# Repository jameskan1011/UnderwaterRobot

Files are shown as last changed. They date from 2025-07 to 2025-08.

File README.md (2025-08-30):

# AquaVise: Underwater Inspection Robot

AquaVise is a compact and intelligent underwater Remotely Operated Vehicle (ROV) developed for corrosion inspection and monitoring tasks, specifically within nuclear reactor pools. It combines mechanical agility, advanced sensing, and intelligent software to detect corrosion visually and maintain stable maneuverability in challenging underwater environments.

🏆 **Capstone Theme Award** at Universiti Teknologi Malaysia  
🏆 **Gold Award** in International Virtual Competition of Creative & Innovative Idea (IVCCII 2025)  
🏆 **Gold Medal** in Virtual Innovation Competition 2025  

---
WhatsApp Image 2025-03-29 at 11 39 36 PM (1) (1)
WhatsApp Image 2025-03-29 at 11 39 37 PM

## 📽️ Demonstration

- **Test in Aquarium:**  
https://github.com/user-attachments/assets/d291c60b-21bb-4c5e-aba0-56c1710979f3

- **Pipe Corrosion Detected:**  
corrosion2_crop
corrosion1_crop

- **Adjustable Camera:**
[ezgif-14e0a4dfad839b.webm](https://github.com/user-attachments/assets/6dd5c388-9fd7-4827-bece-901261d9a31d)

---

## 🚀 Features

- **Corrosion Detection**  
  Utilizes OpenCV-based color thresholding to detect yellow-hued corrosion spots.

- **IMU Stabilization**  
  The MPU6050 IMU ensures stability through real-time pitch and roll correction.

- **Compact 3D-Printed Design**  
  The PLA body with epoxy coating is lightweight, waterproof, and environmentally conscious.

- **Four Thruster System**  
  Ensures 6-DOF movement for optimal maneuverability in confined or dynamic underwater spaces.

- **Integrated Control**  
  Arduino Mega and Raspberry Pi Pico combination enables seamless control and sensor data handling.

- **Real-Time Monitoring**  
  Camera feed with corrosion highlight overlay, live water temperature display, and adjustable servo-driven camera angle.

---

## 🛠️ Hardware Overview

| Component | Description |
|---|---|
| MCU | Arduino Mega + Raspberry Pi Pico |
| Sensors | MPU6050 IMU, Waterproof Thermometer |
| Camera | Endoscope with servo for angle control |
| Motors | 4 Brushed Motors with Propellers |
| Motor Drivers | Dual-channel H-bridge drivers |
| Power Supply | 12.6V 9800mAh Li-Po Battery |
| Chassis | PLA 3D Printed, Coated with Epoxy Resin|

---

## 💻 Software Components

- **Python (Raspberry Pi):**  
  - IMU data processing  
  - Corrosion detection using HSV filtering  
  - UART serial communication to Arduino

- **Arduino C++ (Arduino Mega):**  
  - Joystick handling  
  - Thruster control based on IMU commands  
  - Servo motor positioning for camera

---

## 🧪 Test Highlights

- **Lab Testing:** Corrosion detection software detects yellow regions on test surfaces with adjustable HSV trackbars.
- **On-Site Testing:**  
  - Conducted in aquarium with variable lighting and water clarity.  
  - Detection accuracy improved with real-time HSV tuning via GUI sliders.

---

## ⚙️ System Architecture



---

## 🗺️ Future Improvements

- Replace current thrusters with high-torque waterproof models.
- Use modular ballast containers for adjustable buoyancy.
- Add leak detection sensors with moisture-triggered failsafe shutoff.
- Refine body design for easier maintenance and internal access.
- Upgrade to wireless control with robust data transmission.

---

## 📅 Project Timeline

- Week 1–2: Planning, research & user analysis  
- Week 3–4: Design & CAD modeling  
- Week 5–8: Assembly, coding, integration  
- Week 9–10: Testing, optimization  
- Week 11: Presentation & award recognition  

---

## 👨‍🔧 Authors

- **Kan Chang Fei**  
- **Aina Nuha Binti Che Mahadzir**  
- **Nourhan Hatem Mohammed**  
- **Supervisor:** Assoc. Prof. Ts. Dr. Anita Binti Ahmad  
- Faculty of Electrical Engineering, Universiti Teknologi Malaysia

---

## 📜 License

This project is for academic use. Please contact the authors for permissions on reproduction or distribution.

---

## 📎 References

1. [Motherboard: Engineering the Ultimate Robotic Fish](https://www.youtube.com/watch?v=9ISGXe0Vl5A)  
2. [Science Buddies: Build an Underwater ROV](https://www.youtube.com/watch?v=wRco4tGXrzw)  
3. [CPSdrone: 3D Printed Submarine DIY](https://www.youtube.com/watch?v=arTLho86huQ)

---

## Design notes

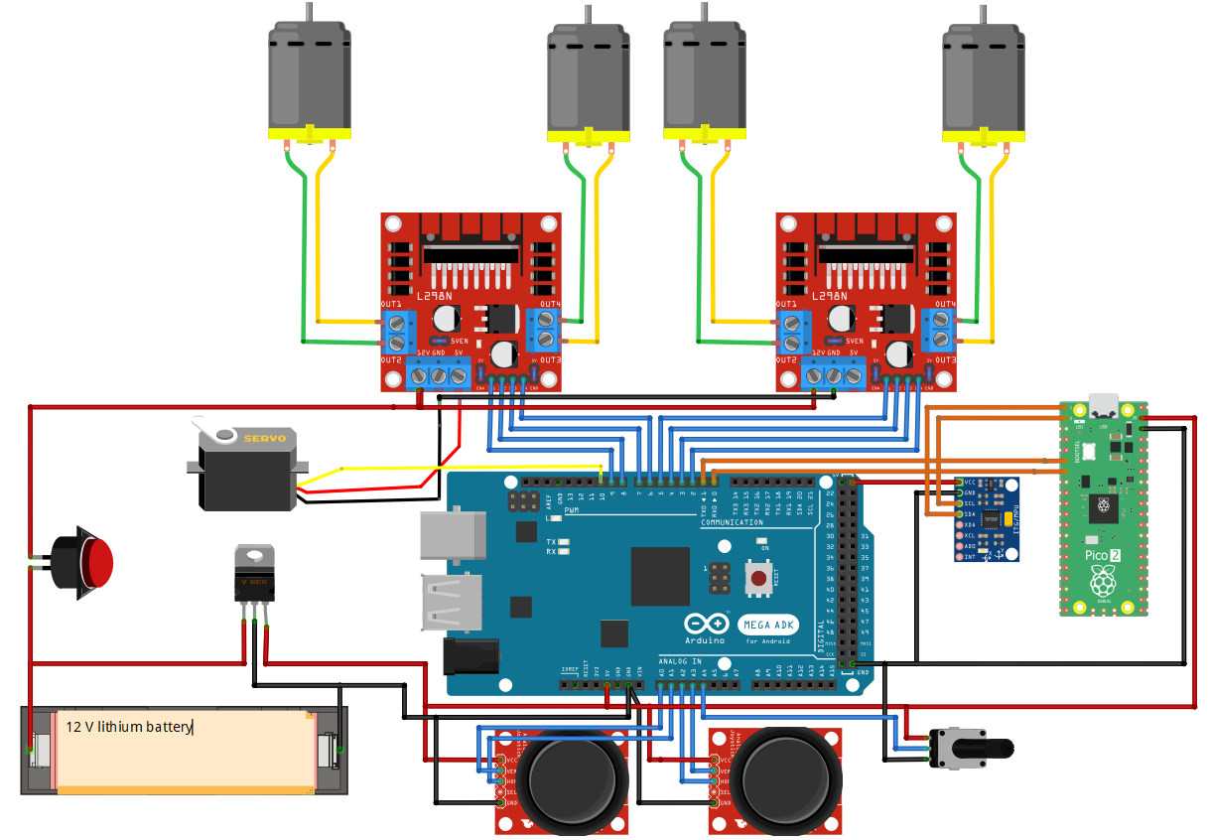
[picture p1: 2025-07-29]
schematic.png

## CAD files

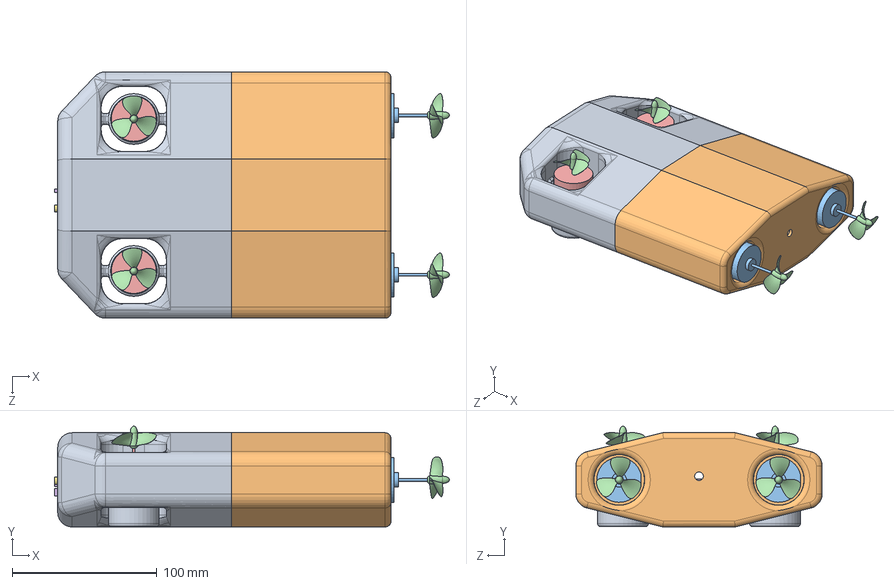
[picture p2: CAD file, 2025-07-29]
3d model/Assem2.SLDASM
272.5 x 69.6 x 170.0 mm
Part1 (latest)
part2 (latest)
Motor_holder x 2
三叶螺旋桨 x 4
thruster 2 x 2
SG90servogövde
camera
MDD3A x 2
pcb.step

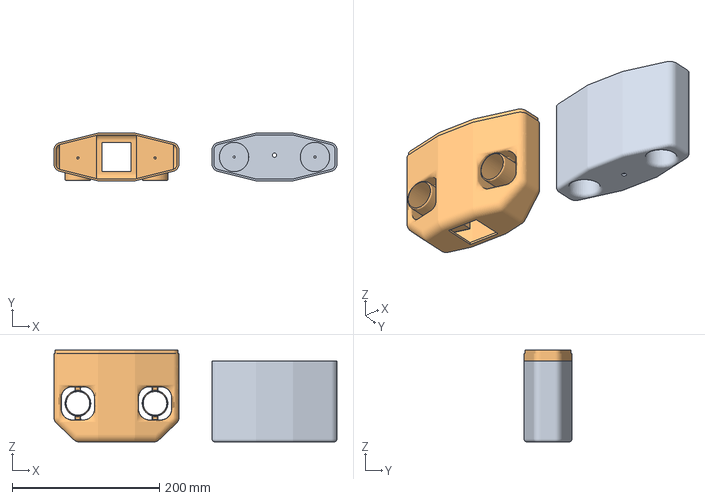
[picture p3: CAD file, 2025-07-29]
3d model/ROV.gcode.3mf
385.0 x 65.0 x 125.0 mm
part2 (latest).STL
Part1 (latest).STL

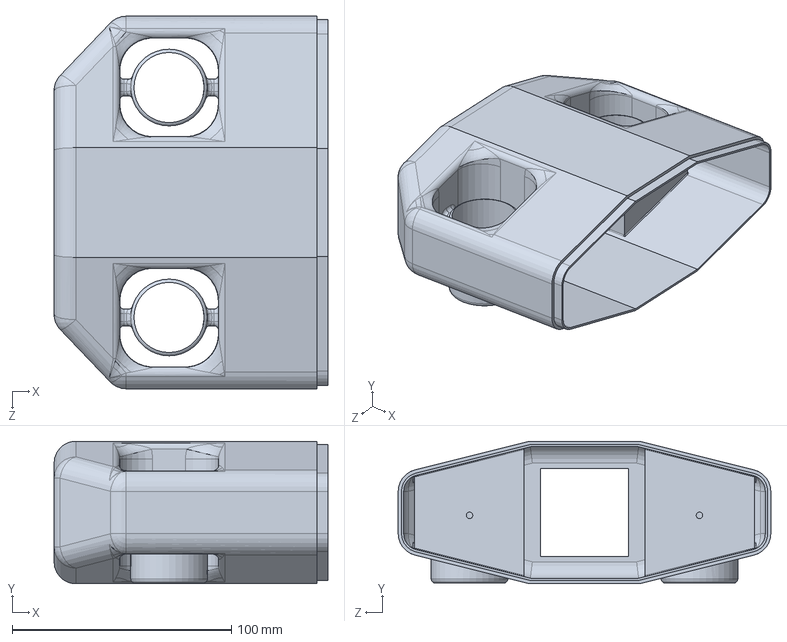
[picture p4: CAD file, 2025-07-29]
3d model/Part1 (latest).SLDPRT
125.0 x 65.0 x 170.0 mm

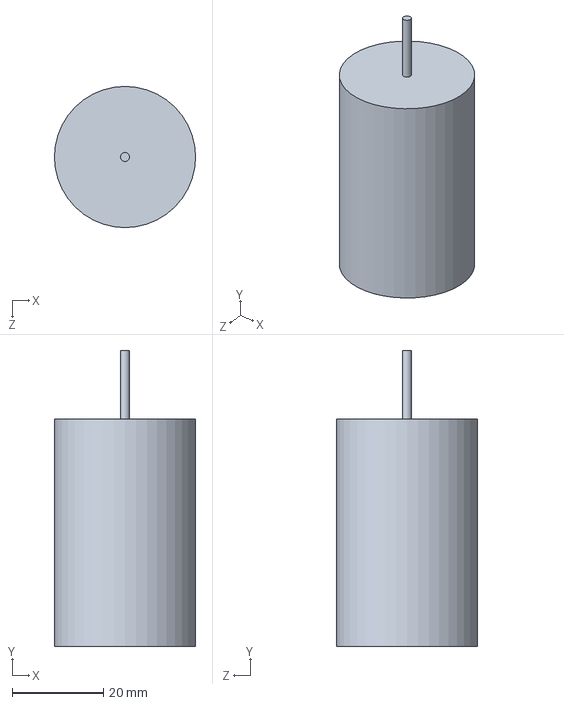
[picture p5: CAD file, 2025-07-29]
3d model/thruster 2.SLDPRT
31.0 x 65.0 x 31.0 mm

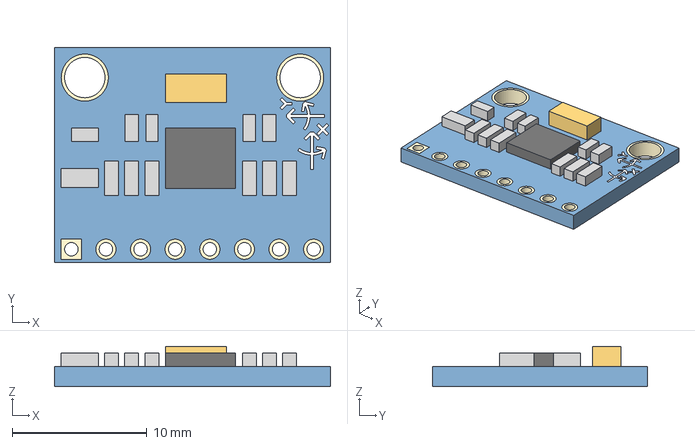
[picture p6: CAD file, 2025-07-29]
3d model/MPU_6050.step
20.5 x 16.0 x 3.00 mm

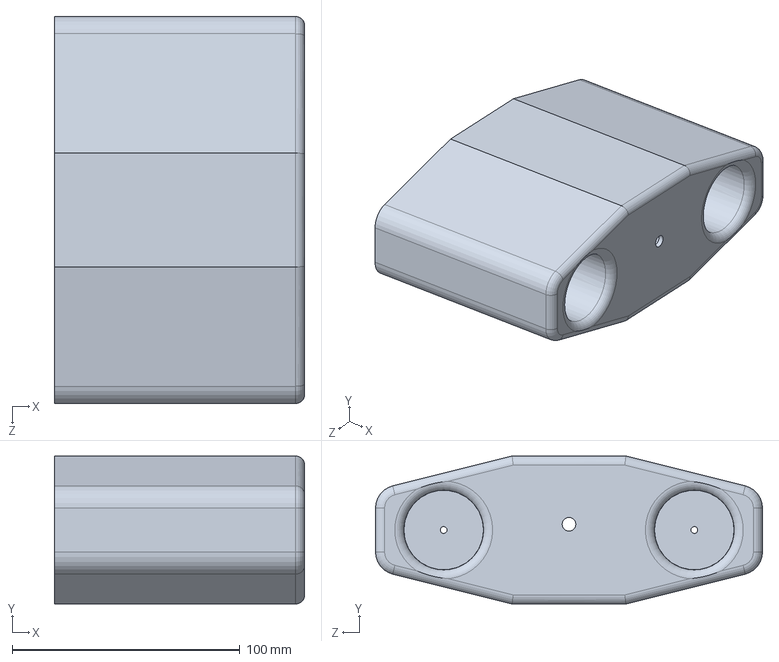
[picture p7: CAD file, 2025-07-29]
3d model/part2 (latest).SLDPRT
110.0 x 65.0 x 170.0 mm

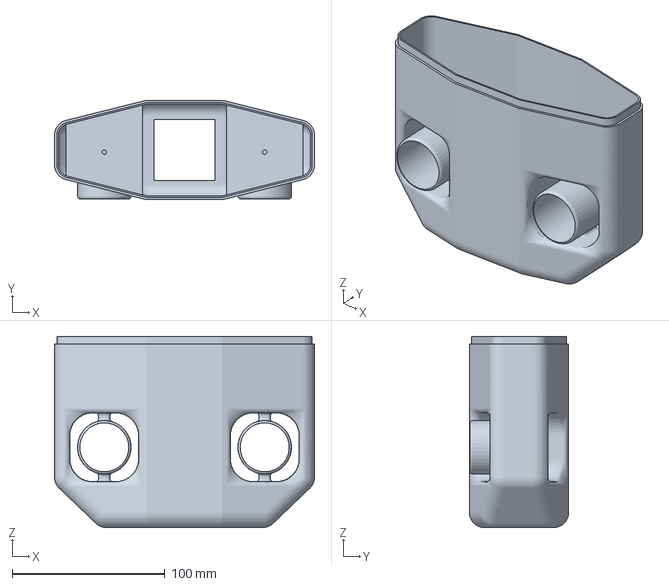
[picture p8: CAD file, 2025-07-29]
3d model/Front_body.3mf
170.0 x 65.0 x 125.0 mm

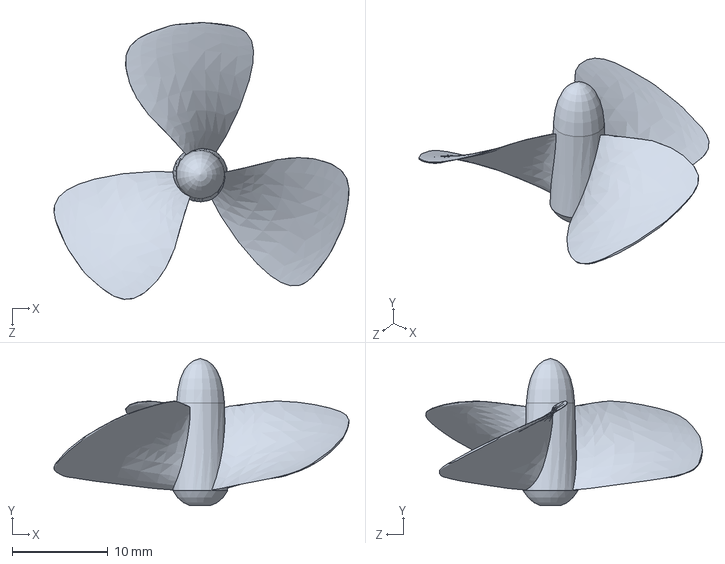
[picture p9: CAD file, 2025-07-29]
3d model/三叶螺旋桨.SLDPRT
30.8 x 15.3 x 28.9 mm

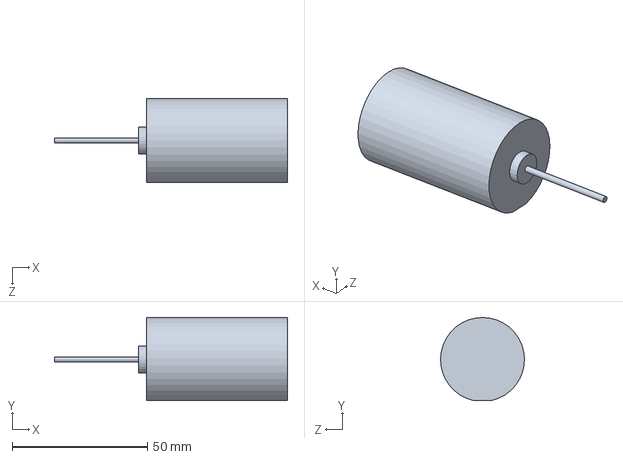
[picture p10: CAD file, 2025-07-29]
3d model/Motor_holder.SLDPRT
86.0 x 30.6 x 31.0 mm

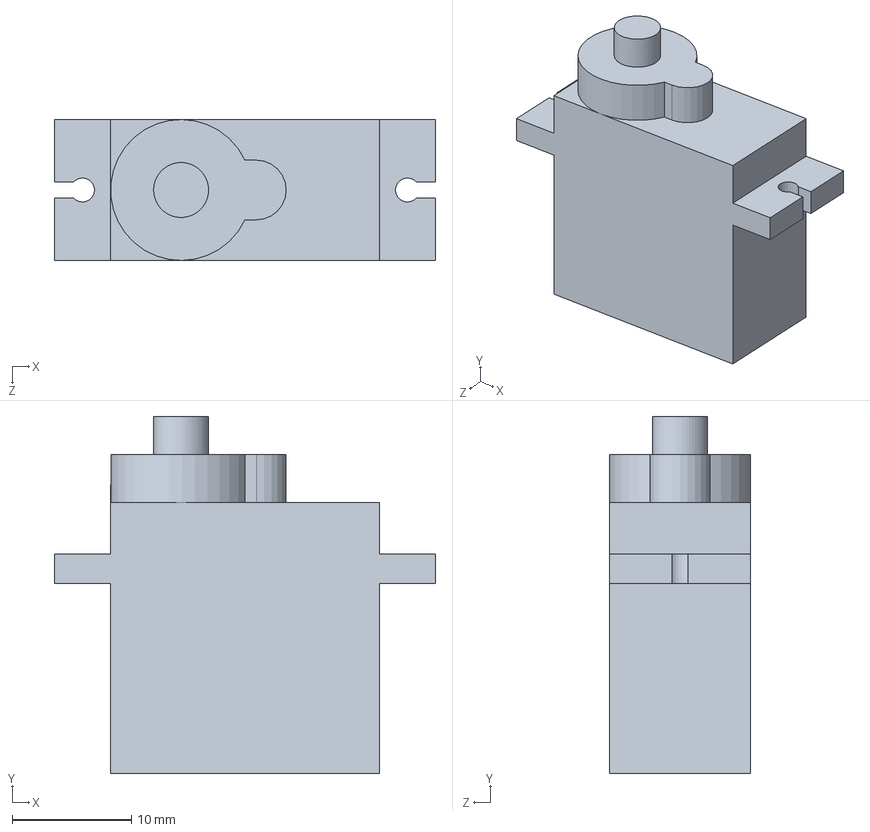
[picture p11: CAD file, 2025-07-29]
3d model/SG90servogövde.SLDPRT
31.9 x 29.9 x 11.8 mm

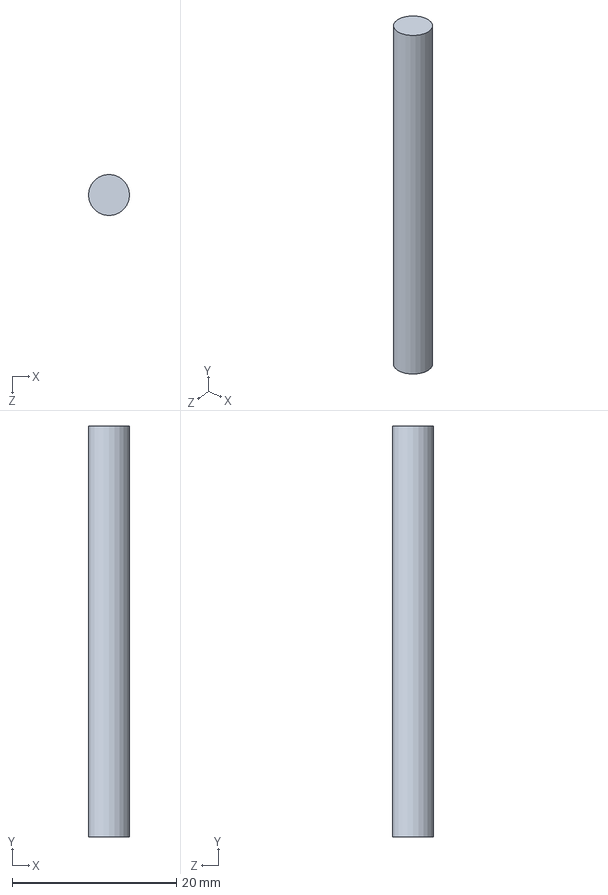
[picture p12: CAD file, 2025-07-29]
3d model/camera.SLDPRT
5.00 x 50.0 x 5.00 mm

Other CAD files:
3d model/ROV.3mf
3d model/rear_body.3mf
3d model/Part1 (latest).STL
3d model/part2 (latest).STL

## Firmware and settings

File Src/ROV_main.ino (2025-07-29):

#include <Servo.h>
#include <SoftwareSerial.h>
SoftwareSerial mySerial(0, 1); // RX, TX for Raspberry Pi Pico

Servo myservo;  
int potpin = A5;  
int val;    

#define joystickX1  A0
#define joystickY1  A1
#define joystickX2  A2
#define joystickY2  A3

#define Thrust_pwm1  2
#define Thrust_pwm2  3
#define Yaw_pwm1  4
#define Yaw_pwm2  5
#define Pitch_pwm1  6
#define Pitch_pwm2  7
#define Roll_pwm1  8
#define Roll_pwm2  9

int motor_controlX1;
int motor_controlY1;
int motor_controlX2;
int motor_controlY2;

void setup() {
  myservo.attach(12);

  pinMode(Thrust_pwm1, OUTPUT);
  pinMode(Thrust_pwm2, OUTPUT);
  pinMode(Yaw_pwm1, OUTPUT);
  pinMode(Yaw_pwm2, OUTPUT);
  pinMode(Pitch_pwm1, OUTPUT);
  pinMode(Pitch_pwm2, OUTPUT);
  pinMode(Roll_pwm1, OUTPUT);
  pinMode(Roll_pwm2, OUTPUT);

  Serial.begin(9600);
  delay(500);
}

void loop() {
  // Read potentiometer and map to servo angle//
  val = analogRead(potpin);            
  val = map(val, 0, 1023, 0, 180);    
  myservo.write(90); 
  delay(15);  

  if (Serial.available()){
    String command = Serial.readStringUntil('\n');
        Serial.println(command);
        if (command == "M1- M2-") {
            digitalWrite(Thrust_pwm1, HIGH);
            digitalWrite(Thrust_pwm2, LOW);
            digitalWrite(Yaw_pwm1, HIGH);
            digitalWrite(Yaw_pwm2, LOW);
        } else if (command == "M1+ M2+") {
            digitalWrite(Thrust_pwm1, LOW);
            digitalWrite(Thrust_pwm2, HIGH);
            digitalWrite(Yaw_pwm1, HIGH);
            digitalWrite(Yaw_pwm2, LOW);
        } else if (command == "M1+ M2-") {
            digitalWrite(Thrust_pwm1, HIGH);
            digitalWrite(Thrust_pwm2, LOW);
            digitalWrite(Yaw_pwm1, HIGH);
            digitalWrite(Yaw_pwm2, LOW);
        } else if (command == "M1- M2+") {
            digitalWrite(Thrust_pwm1, LOW);
            digitalWrite(Thrust_pwm2, HIGH);
            digitalWrite(Yaw_pwm1, HIGH);
            digitalWrite(Yaw_pwm2, LOW);
        }
  
  
  else{
  // divide joystick reading by 2//
  motor_controlX1 = analogRead(joystickX1) >> 1; // Scale to 0-511
  motor_controlY1 = analogRead(joystickY1) >> 1; // Scale to 0-511

  motor_controlX2 = analogRead(joystickX2) >> 1; // Scale to 0-511
  motor_controlY2 = analogRead(joystickY2) >> 1; // Scale to 0-511

  //Convert joysticks reading into Throttle, Yaw, Roll and Pitch//

  // Throttle Control (Y-axis)
  int throttleA = 0, throttleB = 0;
  if (motor_controlY1 > 320) {
    throttleA = motor_controlY1 - 256; // Forward thrust
    throttleB = motor_controlY1 - 256; // Forward thrust
  } else if (motor_controlY1 < 150) {
    throttleA = -(255 - motor_controlY1); // Reverse thrust
    throttleB = -(255 - motor_controlY1); // Reverse thrust
  }

  // Yaw Control (X-axis)
  int yawA = 0, yawB = 0;
  if (motor_controlX1 > 320) {
    yawA = motor_controlX1 - 256; // Positive yaw
    yawB = motor_controlX1 - 256;
  } else if (motor_controlX1 < 150) {
    yawA = -(255 - motor_controlX1); // Negative yaw
    yawB = -(255 - motor_controlX1);
  }

    // Roll Control (X-axis)
  int rollA = 0, rollB = 0;
  if (motor_controlX2 > 320) {
    rollA = motor_controlX2 - 256; // Positive yaw
    rollB = motor_controlX2 - 256;
  } else if (motor_controlX2 < 150) {
    rollA = -(255 - motor_controlX2); // Negative yaw
    rollB = -(255 - motor_controlX2);
  }

      // Pitch Control (Y-axis)
  int PitchA = 0, PitchB = 0;
  if (motor_controlY2 > 320) {
    PitchA = motor_controlY2 - 256; // Positive yaw
    PitchB = motor_controlY2 - 256;
  } else if (motor_controlY2 < 150) {
    PitchA = -(255 - motor_controlY2); // Negative yaw
    PitchB = -(255 - motor_controlY2);
  }

  // Combine throttle and yaw for  motorA, B//
  int motorA = constrain(throttleA + yawA, -255, 255);
  int motorB = constrain(throttleB - yawB, -255, 255);

  // Combine pitch and roll for each motorC, D//
  int motorC = constrain(PitchA + rollA, -255, 255);
  int motorD = constrain(PitchB - rollB, -255, 255);

  //Motor PWM and direction control logic//

  // Set motor A
  if (motorA > 0) {
    analogWrite(Thrust_pwm1, motorA);
    digitalWrite(Thrust_pwm2, LOW);
  } else if (motorA < 0) {
    analogWrite(Thrust_pwm2, -motorA);
    digitalWrite(Thrust_pwm1, LOW);
  } else {
    digitalWrite(Thrust_pwm1, LOW);
    digitalWrite(Thrust_pwm2, LOW);
  }

  // Set motor B
  if (motorB > 0) {
    analogWrite(Yaw_pwm1, motorB);
    digitalWrite(Yaw_pwm2, LOW);
  } else if (motorB < 0) {
    analogWrite(Yaw_pwm2, -motorB);
    digitalWrite(Yaw_pwm1, LOW);
  } else {
    digitalWrite(Yaw_pwm1, LOW);
    digitalWrite(Yaw_pwm2, LOW);
  }

    // Set motor C
  if (motorC > 0) {
    analogWrite(Pitch_pwm1, motorC);
    digitalWrite(Pitch_pwm2, LOW);
  } else if (motorC < 0) {
    analogWrite(Pitch_pwm2, -motorC);
    digitalWrite(Pitch_pwm1, LOW);
  } else {
    digitalWrite(Pitch_pwm1, LOW);
    digitalWrite(Pitch_pwm2, LOW);
  }

    // Set motor D
  if (motorD > 0) {
    analogWrite(Roll_pwm1, motorD);
    digitalWrite(Roll_pwm2, 0);
  } else if (motorD < 0) {
    analogWrite(Roll_pwm2, -motorD);
    digitalWrite(Roll_pwm1, 0);
  } else {
    digitalWrite(Roll_pwm1, 0);
    digitalWrite(Roll_pwm2, 0);
  }
  }
  }
}

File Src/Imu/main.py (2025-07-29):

LED = machine.Pin("LED", machine.Pin.OUT)
LED.on()

from imu import MPU6050
from time import sleep
from machine import Pin, I2C
import math


i2c = I2C(0, sda=Pin(0), scl=Pin(1), freq=400000)
imu = MPU6050(i2c)
i2c.scan()

#thruster adjustment logic
def adjust_thrusters(pitch, roll):
    # Baseline (horizontal reference)
    pitch_baseline = 0
    roll_baseline = 0

    # Threshold for sensitivity
    threshold = 2.0  # degrees

    pitch_error = pitch - pitch_baseline
    roll_error = roll - roll_baseline

    # Horizontal stabilization logic
    if abs(pitch_error) > threshold:
        if pitch_error > 0:
            print("m1 and m2 increased ")
        else:
            print("m1 and m2 decrease ")

    if abs(roll_error) > threshold:
        if roll_error > 0:
            print("m1 decrease , m2 increase ")
        else:
            print("m1 increase , m2 decrease ")


while True:
    ax=round(imu.accel.x,2)
    ay=round(imu.accel.y,2)
    az=round(imu.accel.z,2)
    gx=round(imu.gyro.x)
    gy=round(imu.gyro.y)
    gz=round(imu.gyro.z)
    tem=round(imu.temperature,2)
    
    print("ax",ax,"\t","ay",ay,"\t","az",az,"\t","gx",gx,"\t","gy",gy,"\t","gz",gz,"\t","Temperature",tem,"        ",end="\r")
    
    sleep(0.2)
    
    pitch = math.atan2(ax, math.sqrt(ay*2 + az*2)) * 180 / math.pi
    roll = math.atan2(ay, math.sqrt(ax*2 + az*2)) * 180 / math.pi
    
    print(f"Pitch: {pitch:.2f}, Roll: {roll:.2f}")
    adjust_thrusters(pitch, roll)
    
    sleep(1)
